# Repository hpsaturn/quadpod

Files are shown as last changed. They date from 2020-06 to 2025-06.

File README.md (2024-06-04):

# Quadpod ESP32 Bluetooth Alternative

One year ago, in the middle of Covid19, with my [brother](https://www.youtube.com/user/svporion/featured) we did this robot alternative, it is a remix of a popular SG90 12DOF robot in [Thingiverse](https://www.thingiverse.com/thing:3122758). My brother did again some 3d print parts and I did the migration from two Arduino micro controllers to only one micro controller using the ESP32 with FreeRTOS tasks. Also the robot uses a Bluetooth connection for improve usability and power consumption, but is possible controlling it with WiFI connection too.

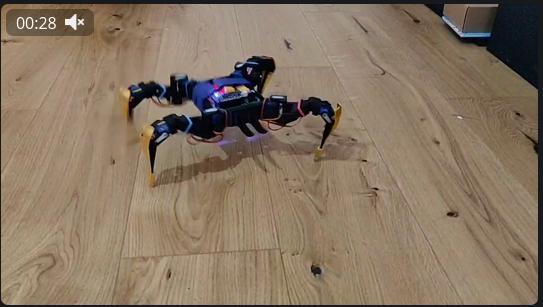
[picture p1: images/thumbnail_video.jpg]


# NOTE:

The robot is useful for understand many things, and is funny making it, but the speed and performance is a little bit buggy, we recommended using **MG90S** servos instead SG90 plastic servo, or maybe using better servos, also the hexapod config will be better, but again, for learning this model is fine.

# 3D Print

The last improved parts are here in this repository, but you also to able some details and photos of this models in the our [Thingiverse](https://www.thingiverse.com/thing:4644707) page.

# Electric diagram

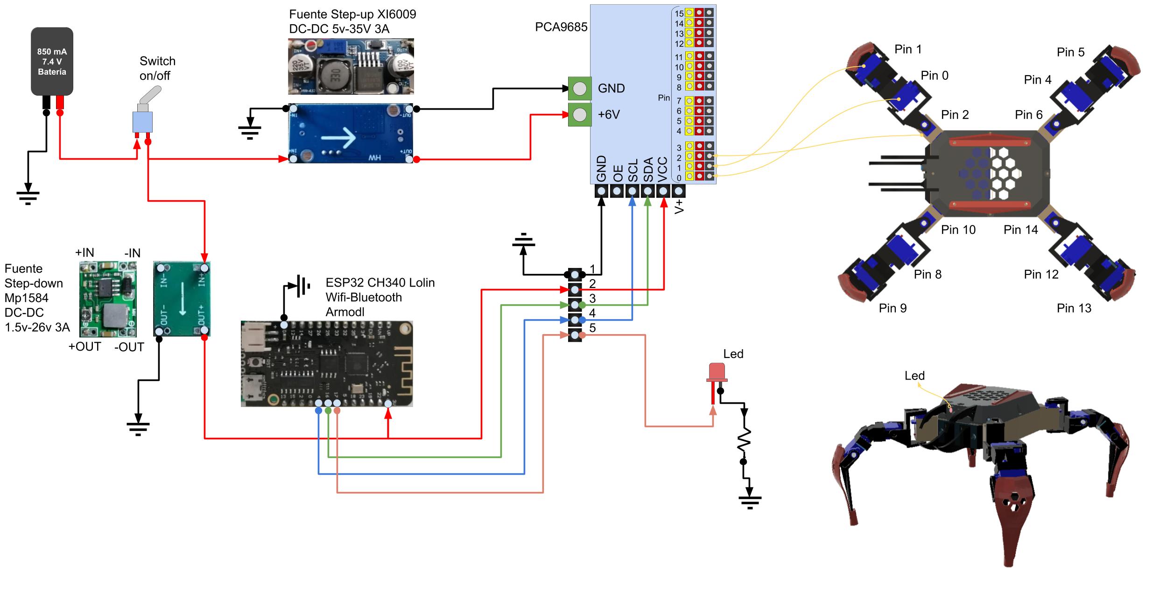
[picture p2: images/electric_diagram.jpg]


# Build and Flashing

First to all, please install PlatformIO with your favourite IDE (i.e. VSCode). Follow [this](https://platformio.org/platformio-ide) instructions. Also, you should install [git](http://git-scm.com/) in your system.

## Clone the repo

```sh
git clone https://github.com/hpsaturn/quadpod.git
```

Connect the ESP32 via USB. In Windows 10, drivers are installed automatically. I guess with other OS will be automatically installed too.

Open cloned folder with your PlatformIO IDE and build & upload it. For details please see the [documentation](https://docs.platformio.org/en/latest/integration/ide/vscode.html#quick-start), but the process flow is more easy than Arduino IDE flow, but you can also import it to the Arduino IDE if you want.

PlatformIO Build tool

Or after clone also you can build and upload the current firmware from CLI:

```shell
cd quadpod && pio run --target upload
```

# Bluetooth control

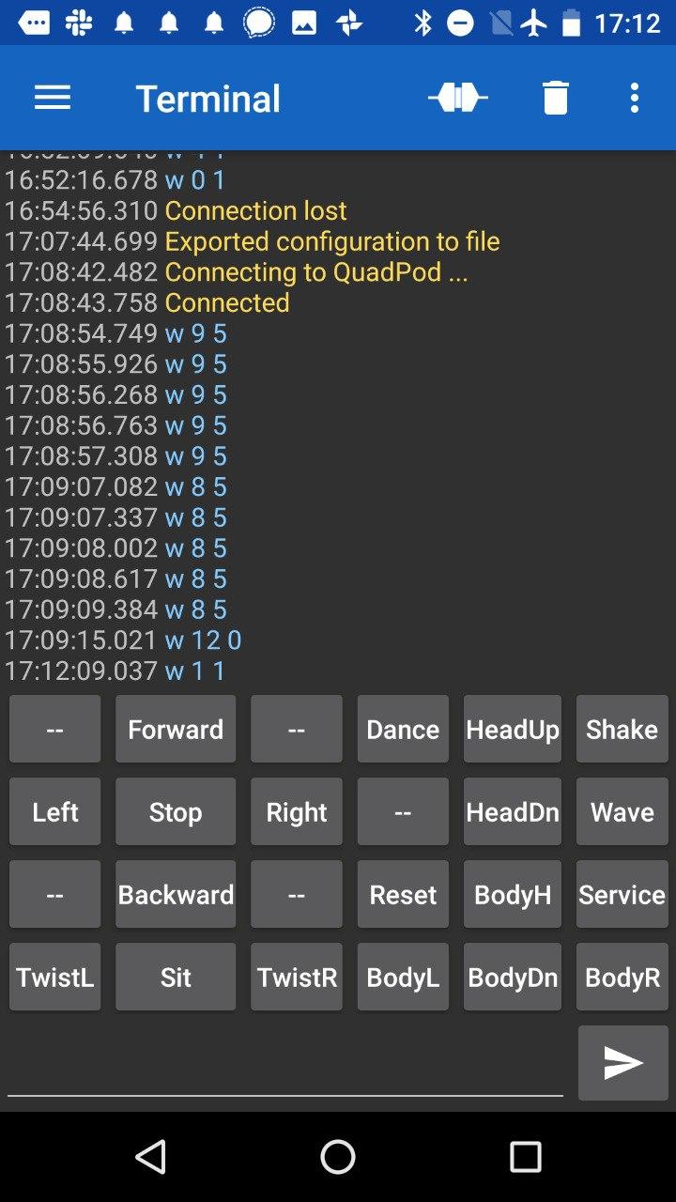
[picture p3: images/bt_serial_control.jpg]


For now, you can use this app: [Serial Bluetooth Terminal](https://play.google.com/store/apps/details?id=de.kai_morich.serial_bluetooth_terminal) and donwload the file `serial_bluetooth_terminal.cfg.txt` that is under `bt` folder of this project, then send it to your phone and import it with this application for get all commands and buttons for controlling the robot.

# Credits

Special thanks to [Santiago Vanegas](https://www.thingiverse.com/alfazoom/designs) for 3D models and many improvements.

---

### Donations:

If you want invite me a coffee in:  

https://hpsaturn.com/about/  
https://paypal.me/hpsaturn

### Or support my initiative

CanAirIO Citizen network for monitoring air quality https://canair.io

---

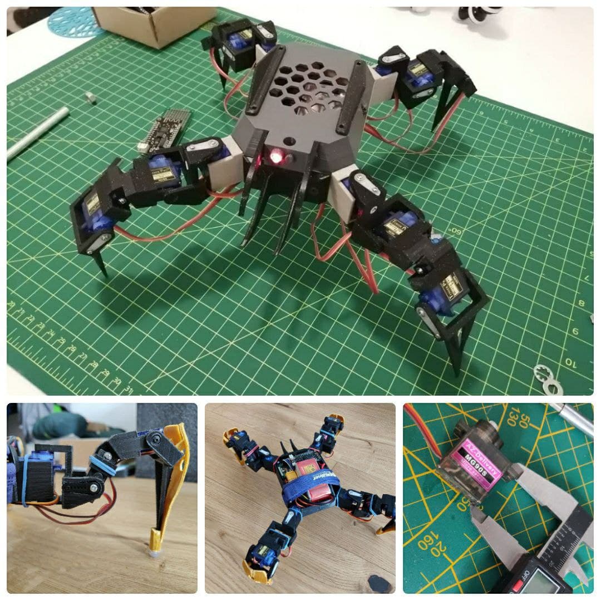
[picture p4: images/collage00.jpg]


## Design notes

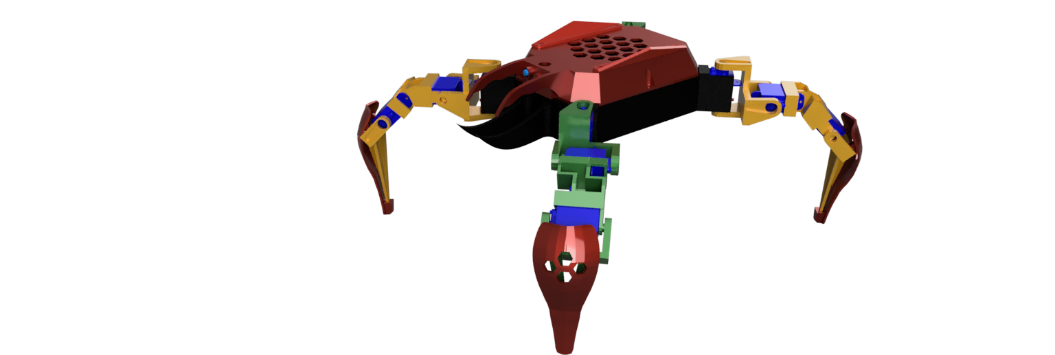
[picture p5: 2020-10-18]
images/Aragog v34.png

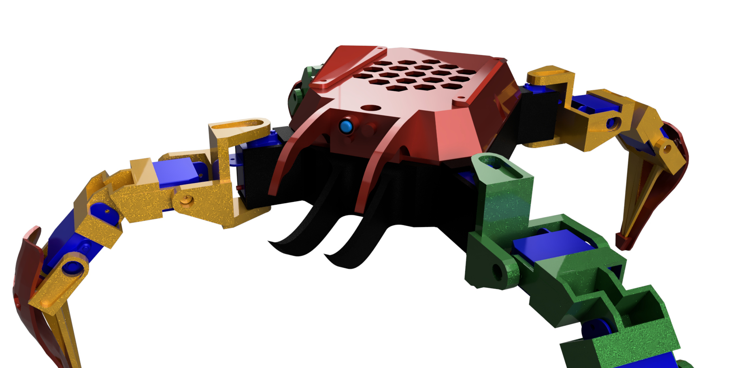
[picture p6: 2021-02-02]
images/3drender.jpg

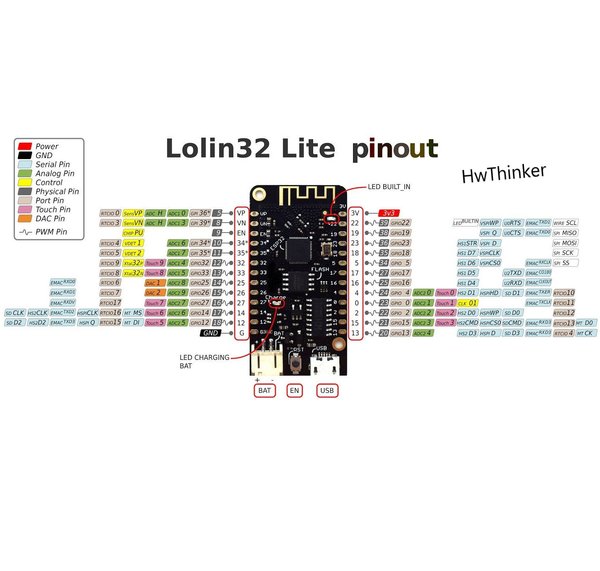
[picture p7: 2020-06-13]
docs/ESP32_WeMos_Lolin32_Lite.jpg

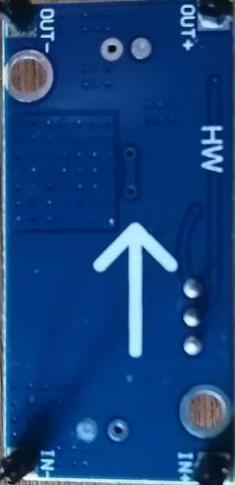
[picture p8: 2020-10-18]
docs/Blue stepdown.jpg

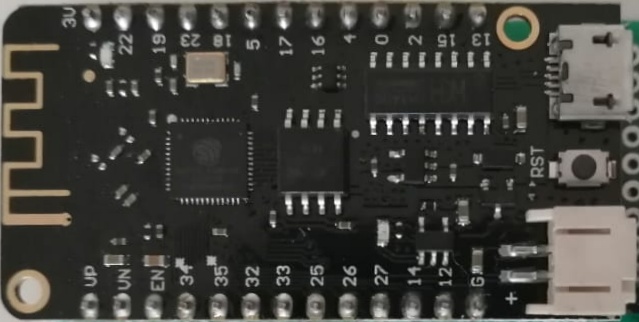
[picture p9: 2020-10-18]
docs/ESP32.jpeg

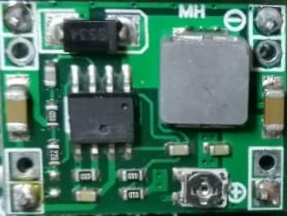
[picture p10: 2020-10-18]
docs/mini stepdown up.jpg

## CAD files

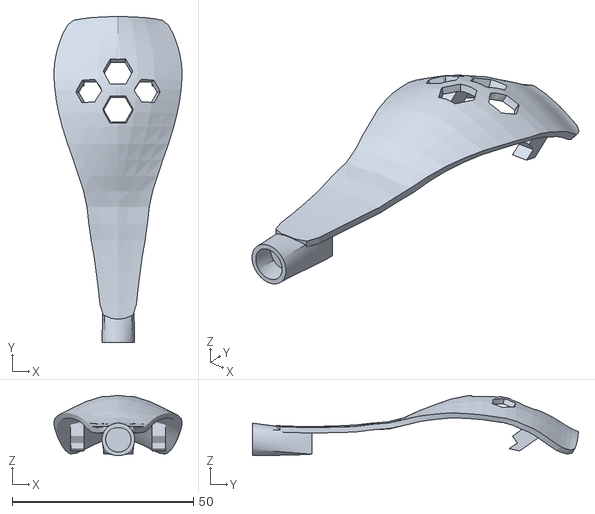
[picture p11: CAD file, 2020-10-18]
models/shield_tap.stl
35.3 x 90.1 x 16.7

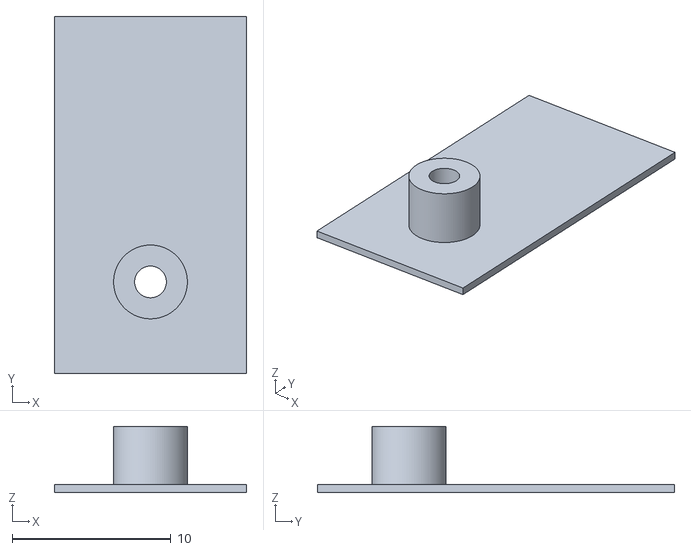
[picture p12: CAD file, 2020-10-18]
models/Insert_body.stl
12.1 x 22.5 x 4.18

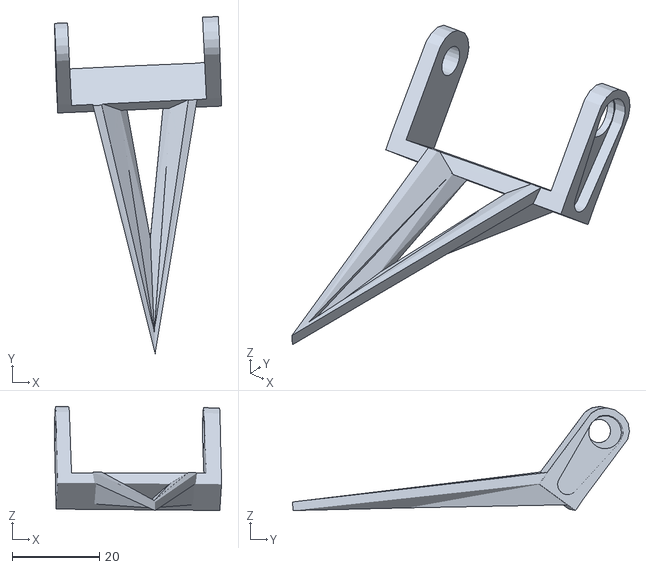
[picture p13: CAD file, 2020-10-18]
models/Foot-a.stl
38.3 x 77.2 x 23.8

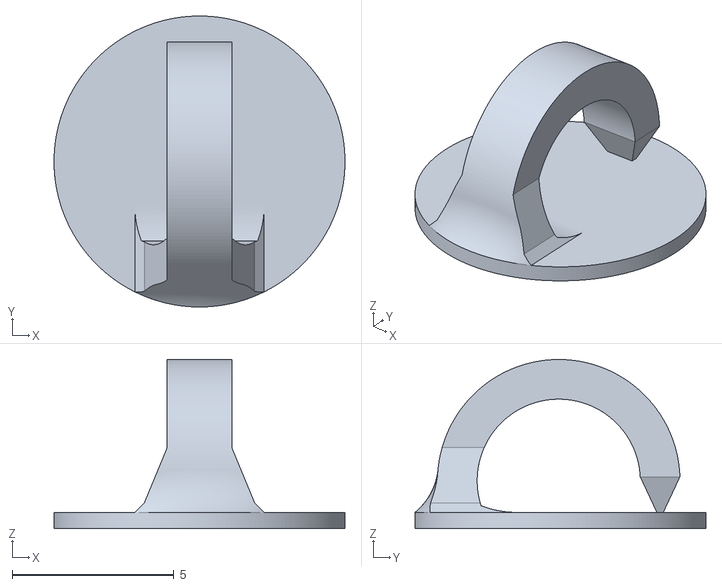
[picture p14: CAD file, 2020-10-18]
models/Pincable.stl
9.00 x 9.00 x 5.23

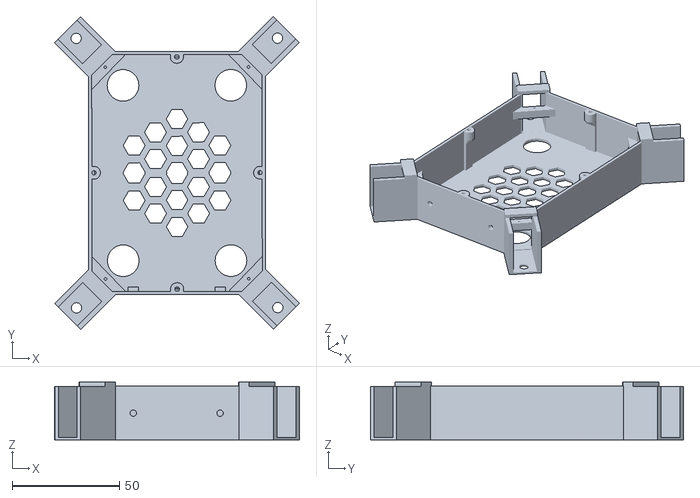
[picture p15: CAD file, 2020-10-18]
models/Body_insert.stl
114.3 x 146.0 x 26.9

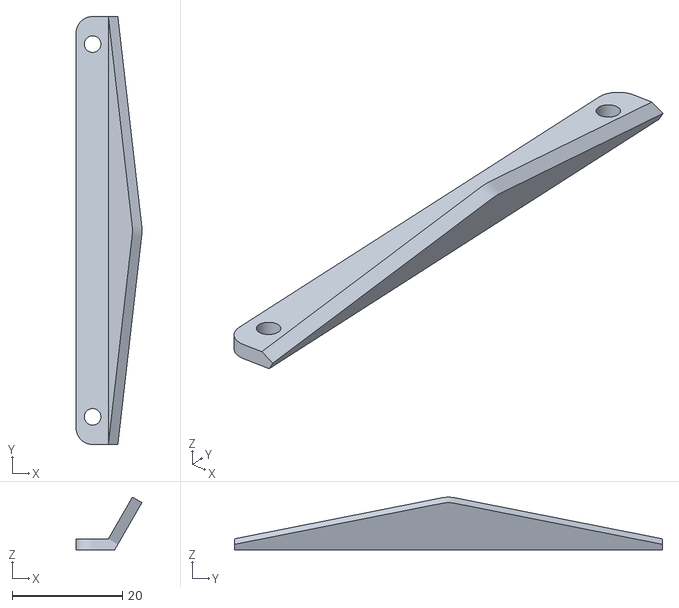
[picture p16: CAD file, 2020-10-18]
models/wings.stl
11.9 x 77.5 x 9.55

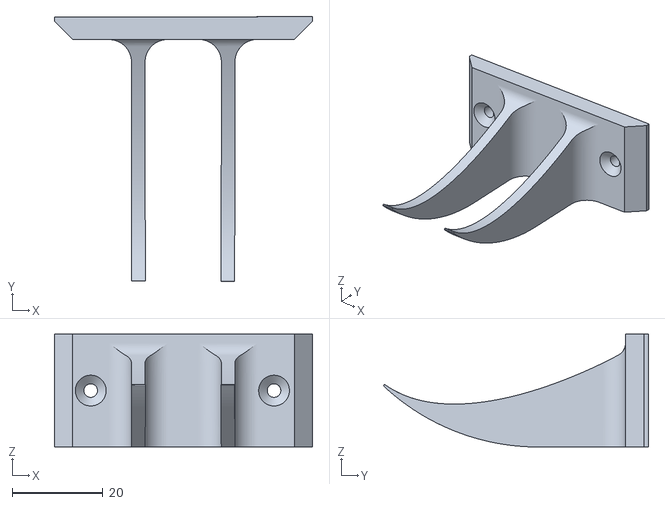
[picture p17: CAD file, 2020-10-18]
models/Tool_Body.stl
57.0 x 58.5 x 25.0

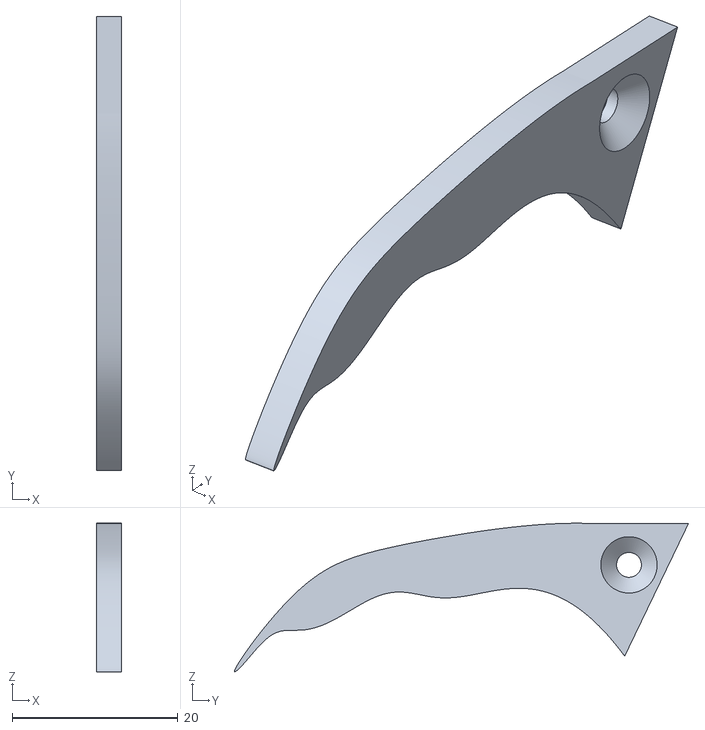
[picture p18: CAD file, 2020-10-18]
models/Tool-sup-izq.stl
3.00 x 54.8 x 17.9

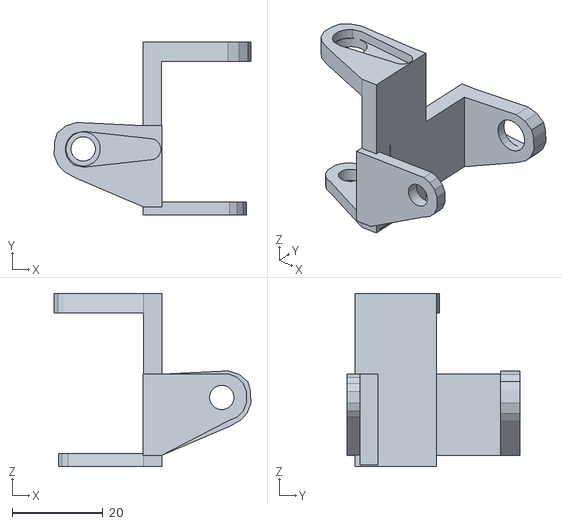
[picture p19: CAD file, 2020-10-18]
models/Hips-a.stl
43.3 x 38.1 x 38.1

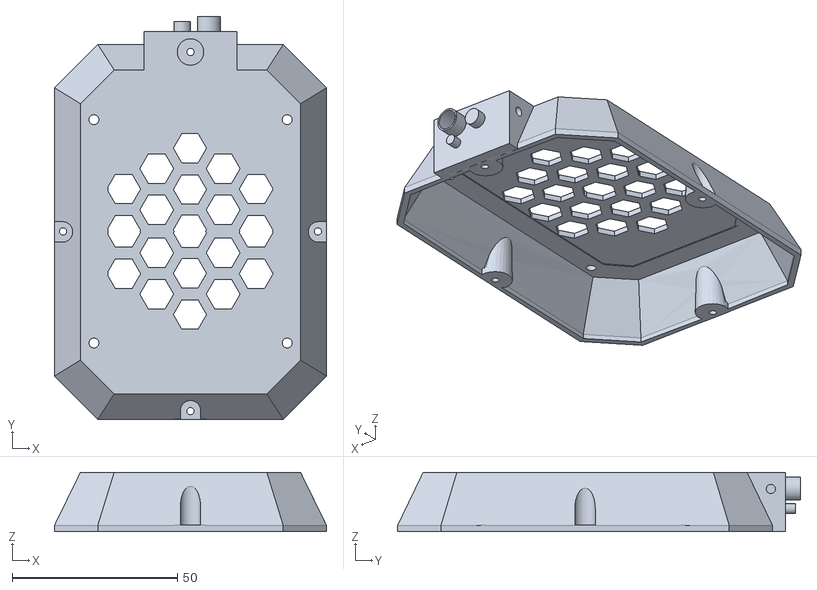
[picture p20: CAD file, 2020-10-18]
models/Cover-led-tool-wings.stl
82.2 x 121.8 x 17.9

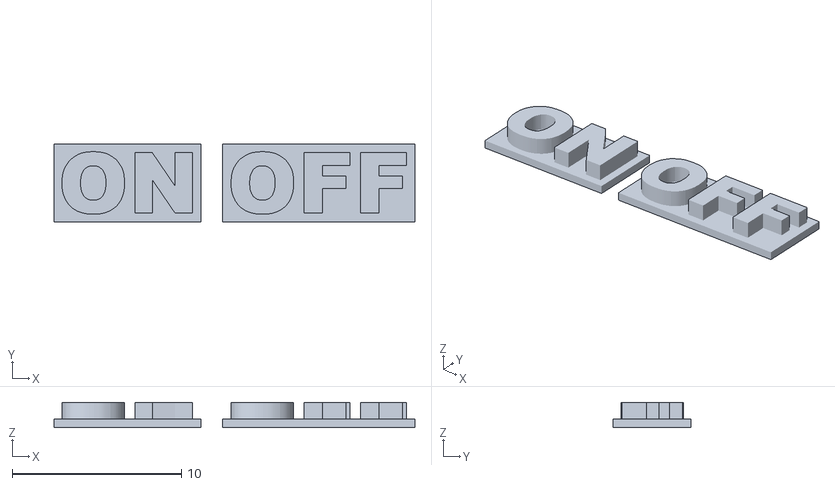
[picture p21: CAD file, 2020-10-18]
models/ON-OFF_label.stl
21.3 x 4.59 x 1.50

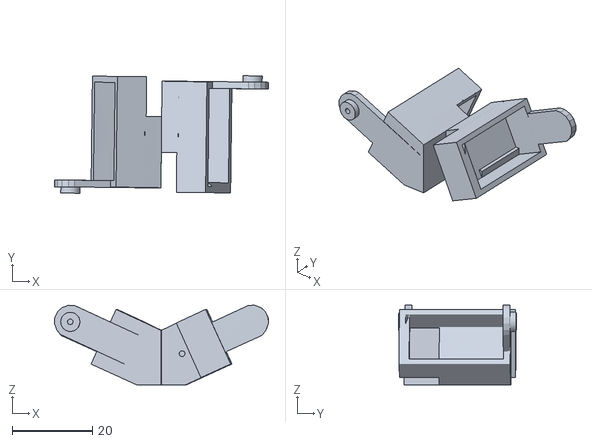
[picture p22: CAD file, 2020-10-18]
models/Thigh-b.stl
53.3 x 29.3 x 19.8

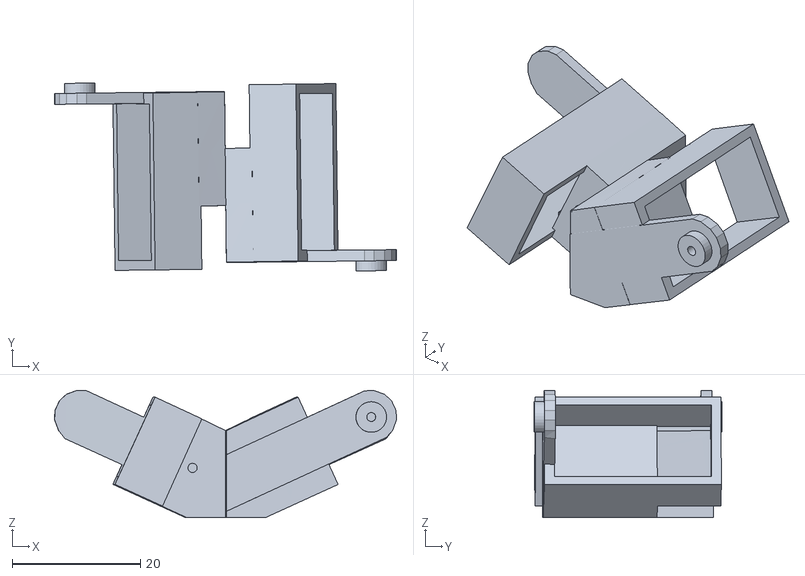
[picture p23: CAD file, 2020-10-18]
models/Thigh-a.stl
53.3 x 29.3 x 19.8

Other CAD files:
models/Tool-sup-der.stl
models/Hips-b.stl
models/Foot-b.stl

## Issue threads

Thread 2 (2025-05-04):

Repository isn´t aviable

joseraymar, 2025-05-04:
Hi, I'm trying to build this robot for the first time and I'm new to this topic. I have a problem: the Adafruit PWM Servo Driver Library links to
https://github.com/MichaelMoskie-Nano/Arduino-SerialCommand.git, but that repository no longer exists.
Do you have another repository or a solution? Thank you for your time.

hpsaturn, 2025-05-04:
mmm, yes, it is true. Mmm, maybe I need fix it freezing the versions of each library. Please try to test with this library:

https://github.com/kroimon/Arduino-SerialCommand.git

if works with this, please let me know to fix this issue. Thanks in advance.

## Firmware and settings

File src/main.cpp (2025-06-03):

/* -----------------------------------------------------------------------------
  - Original Project: Body Movement Crawling robot
  - Original Author:  panerqiang@sunfounder.com
  - Date:  2015/1/27

  - Remix Project by Wilmar
  - Date: 2018/09/25
  - ref: https://www.thingiverse.com/thing:3122758

  - Current version: Bluetooth Alternative with a ESP32
  - Author: @hpsaturn
  - source: https://github.com/hpsaturn/quadpod
--------------------------------------------------------------------------------*/

#include <Arduino.h>

#include <servos.hpp>

void setup() {
  // start serial for debug
  Serial.begin(115200);
  delay(1000);
  Serial.println("===== ROBOT SETUP =====");
  pinMode(LED_BUILTIN, OUTPUT);
  servos_init();
  Serial.println("===== SETUP END =====");
}

void loop() { servos_loop(); }

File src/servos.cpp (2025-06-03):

#include <servos.hpp>

#ifdef ENABLE_BLUETOOTH
BluetoothSerial btSerial;      // Object for Bluetooth
SerialCommand SCmd(btSerial);  // The demo SerialCommand object
#endif

Adafruit_PWMServoDriver pwm = Adafruit_PWMServoDriver();

/* Servos --------------------------------------------------------------------*/
// define 12 servos for 4 legs
// Servo servo[4][3];
// define servos' ports
const int servo_pin[4][3] = {{0, 1, 2}, {4, 5, 6}, {8, 9, 10}, {12, 13, 14}};
/* Size of the robot ---------------------------------------------------------*/
const float length_a = 55;
const float length_b = 77.5;
const float length_c = 27.5;
const float length_side = 71;
const float z_absolute = -28;
/* Constants for movement ----------------------------------------------------*/
const float z_default = -50, z_up = -30, z_boot = z_absolute;
const float x_default = 62, x_offset = 0;
const float y_start = 0, y_step = 40;
const float y_default = x_default;
/* variables for movement ----------------------------------------------------*/
typedef struct {
  float site_now[4][3];     // real-time coordinates of the end of each leg
  float site_expect[4][3];  // expected coordinates of the end of each leg
  float temp_speed[4][3];   // each axis' speed, needs to be recalculated before each movement
  int32_t FRFoot = 0;
  int32_t FRElbow = 0;
  int32_t FRShdr = 0;
  int32_t FLFoot = 0;
  int32_t FLElbow = 0;
  int32_t FLShdr = 0;
  int32_t RRFoot = 0;
  int32_t RRElbow = 0;
  int32_t RRShdr = 0;
  int32_t RLFoot = 0;
  int32_t RLElbow = 0;
  int32_t RLShdr = 0;
  int32_t rest_counter = 0;  //+1/0.02s, for automatic rest
} service_status_t;

service_status_t sst;

float move_speed = 1.4;    // movement speed
float speed_multiple = 1;  // movement speed multiple
const float spot_turn_speed = 4;
const float leg_move_speed = 8;
const float body_move_speed = 3;
const float stand_seat_speed = 1;
// functions' parameter
const float KEEP = 255;
// define PI for calculation
const float pi = 3.1415926;
/* Constants for turn --------------------------------------------------------*/
// temp length
const float temp_a = sqrt(pow(2 * x_default + length_side, 2) + pow(y_step, 2));
const float temp_b = 2 * (y_start + y_step) + length_side;
const float temp_c =
    sqrt(pow(2 * x_default + length_side, 2) + pow(2 * y_start + y_step + length_side, 2));
const float temp_alpha =
    acos((pow(temp_a, 2) + pow(temp_b, 2) - pow(temp_c, 2)) / 2 / temp_a / temp_b);
// site for turn
const float turn_x1 = (temp_a - length_side) / 2;
const float turn_y1 = y_start + y_step / 2;
const float turn_x0 = turn_x1 - temp_b * cos(temp_alpha);
const float turn_y0 = temp_b * sin(temp_alpha) - turn_y1 - length_side;
/* ---------------------------------------------------------------------------*/
String lastComm = "";
boolean print_reach = false;
/*
  - wait one of end points move to expect site
  - blocking function
   ---------------------------------------------------------------------------*/
void wait_reach(int leg) {
  while (1) {
    if (print_reach) {
      Serial.printf("%i now:%f exp:%f\n", leg, sst.site_now[leg][0], sst.site_expect[leg][0]);
      Serial.printf("%i now:%f exp:%f\n", leg, sst.site_now[leg][1], sst.site_expect[leg][1]);
      Serial.printf("%i now:%f exp:%f\n", leg, sst.site_now[leg][2], sst.site_expect[leg][2]);
    }
    if (sst.site_now[leg][0] == sst.site_expect[leg][0]) {
      if (sst.site_now[leg][1] == sst.site_expect[leg][1]) {
        if (sst.site_now[leg][2] == sst.site_expect[leg][2]) {
          break;
        }
      }
    }
  }
}

/*
  - wait all of end points move to expect site
  - blocking function
   ---------------------------------------------------------------------------*/
void wait_all_reach(void) {
  for (int i = 0; i < 4; i++) wait_reach(i);
}

// you can use this function if you'd like to set the pulse length in seconds
// e.g. setServoPulse(0, 0.001) is a ~1 millisecond pulse width. its not precise!
void setServoPulse(uint8_t n, double pulse) {
  double pulselength;
  pulselength = 1000000;  // 1,000,000 us per second
  pulselength /= 60;      // 60 Hz
  pulselength /= 4096;    // 12 bits of resolution
  pulse *= 1000000;       // convert to us
  pulse /= pulselength;
  pwm.setPWM(n, 0, pulse);
}

/*
  - set one of end points' expect site
  - this founction will set temp_speed[4][3] at same time
  - non - blocking function
   ---------------------------------------------------------------------------*/
void set_site(int leg, float x, float y, float z) {
  float length_x = 0, length_y = 0, length_z = 0;

  if (x != KEEP) length_x = x - sst.site_now[leg][0];
  if (y != KEEP) length_y = y - sst.site_now[leg][1];
  if (z != KEEP) length_z = z - sst.site_now[leg][2];

  float length = sqrt(pow(length_x, 2) + pow(length_y, 2) + pow(length_z, 2));

  sst.temp_speed[leg][0] = length_x / length * move_speed * speed_multiple;
  sst.temp_speed[leg][1] = length_y / length * move_speed * speed_multiple;
  sst.temp_speed[leg][2] = length_z / length * move_speed * speed_multiple;

  if (x != KEEP) sst.site_expect[leg][0] = x;
  if (y != KEEP) sst.site_expect[leg][1] = y;
  if (z != KEEP) sst.site_expect[leg][2] = z;
}

/*
  - is_stand
   ---------------------------------------------------------------------------*/
bool is_stand(void) {
  if (sst.site_now[0][2] == z_default)
    return true;
  else
    return false;
}

/*
  - sit
  - blocking function
   ---------------------------------------------------------------------------*/
void sit(void) {
  move_speed = stand_seat_speed;
  for (int leg = 0; leg < 4; leg++) {
    set_site(leg, KEEP, KEEP, z_boot);
  }
  wait_all_reach();
}

/*
  - stand
  - blocking function
   ---------------------------------------------------------------------------*/
void stand(void) {
  move_speed = stand_seat_speed;
  for (int leg = 0; leg < 4; leg++) {
    set_site(leg, KEEP, KEEP, z_default);
  }
  wait_all_reach();
}

/*
  - Body init
  - blocking function
   ---------------------------------------------------------------------------*/
void b_init(void) {
  // stand();
  set_site(0, x_default, y_default, z_default);
  set_site(1, x_default, y_default, z_default);
  set_site(2, x_default, y_default, z_default);
  set_site(3, x_default, y_default, z_default);
  wait_all_reach();
}
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

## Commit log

2020-05-30 platformio basic structure for a ESP32 TTGO T7 v1.3 board
2020-05-30 fixed some header issues and author credits
    [main.cpp]
2020-05-30 added some prototypes and removed timer for now
2020-05-30 refactored in separated files (servos methods)
2020-06-02 refactor servos main process command method
2020-06-03 servos on, but with many issues
    [servos.cpp]
2020-06-03 set frequency like adafruit sample
2020-06-04 not crash more but not works..
    [main.cpp, servos.cpp]
2020-06-04 removed timer, testing only with loop (sound like works)
2020-06-04 added task instead timer
2020-06-05 continous tasker working (servos untested)
2020-06-05 added arm servos status vars to main struct
2020-06-06 first version with any blocker but with many issues
    [main.cpp, servos.cpp]
2020-06-13 added missing esp32 diagram
2020-06-14 fixed task size and bluetooth handling
    [main.cpp, servos.cpp]
2020-06-14 added serial bluetooth terminal app config.
    [serial_bluetooth_terminal.cfg]
2020-07-09 removed sample moving test comments
2021-02-02 added servo improvements note
2025-06-03 testing possible library to replace deprecated serial command lib
    [servos.cpp]
2025-06-03 added build flags suggested on @shyd lib. LED warnning removed
2025-06-03 clang format updated and fixed some issues. Updated ini header
    [main.cpp, servos.cpp]
2026-04-13 freezed to old espressif version for esp32 core
